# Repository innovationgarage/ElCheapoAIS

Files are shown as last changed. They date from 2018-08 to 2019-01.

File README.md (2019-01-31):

# ElCheapoAIS
AIS receiver with DIY antenna and cheap RTL-SDR tuner 

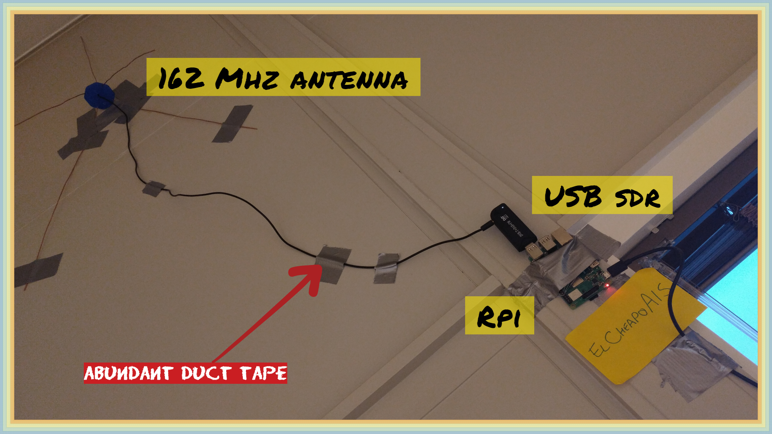
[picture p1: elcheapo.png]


## Quick guide
1. You need: Raspberry Pi, USB RTL SDR tuner, materials for building the antenna
2. Craft the antenna (_see instructions below_)
3. Install Raspbian on the RPi (tested with Stretch 4.14 Lite)
4. Prepare the destination of the AIS data (i.e. create AISHub account: http://www.aishub.net/join-us)
5. Execute `wget -q -O - https://git.io/fpVRc | sudo bash` (Alternatively, you can ignore step 5 and 6 and follow the procedure at the end of this README)
6. Follow the instructions (prepare, calibrate and install using the account details received in step 4)
7. Profit?

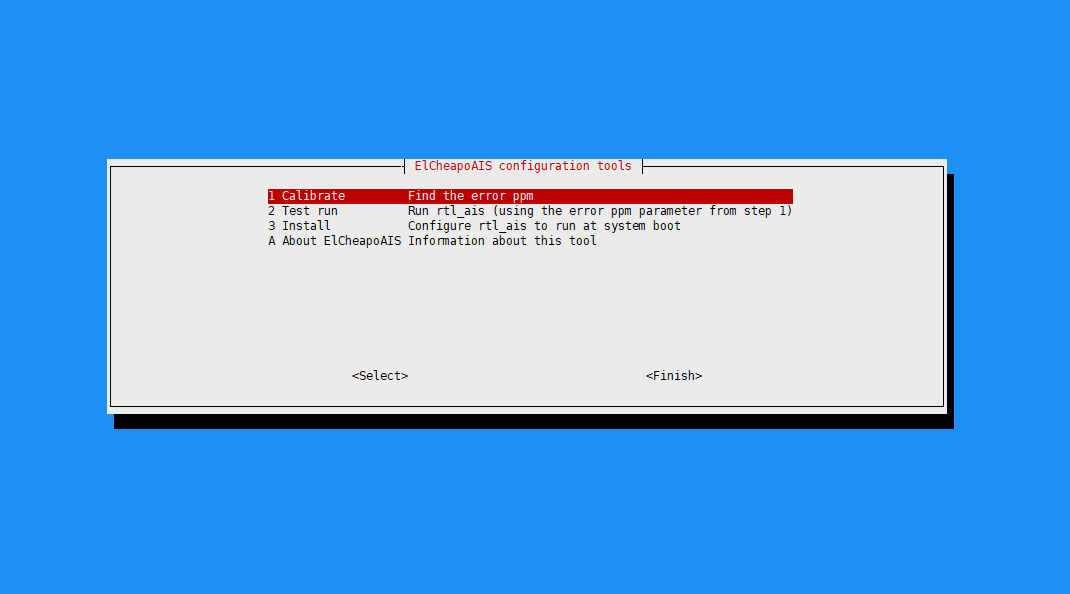
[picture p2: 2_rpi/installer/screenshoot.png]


## Hardware
* Tuner https://www.ebay.com/itm/USB2-0-DAB-FM-DVB-T-RTL2832U-R820T2-SDR-RTL-SDR-Dongle-Stick-Digital-TV-Tun-W8M8/283032648261
* Antenna

### Build the antenna
Measurements, examples and building instructions are available here: https://m0ukd.com/calculators/quarter-wave-ground-plane-antenna-calculator/. The following measurements are for a 162 Mhz antenna (for best results build one around that frequency):

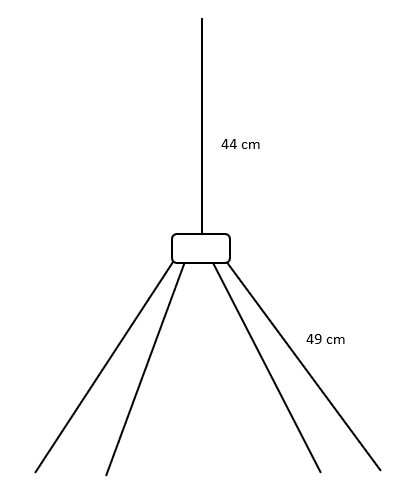
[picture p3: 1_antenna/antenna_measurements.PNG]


You can 3d print the center holder: https://www.thingiverse.com/thing:3099905

## Software

### Windows (Testing)
* AISRecWinFull https://sites.google.com/site/feverlaysoft/home
* OpenCPN
    * Set the same ip and port in OpenCPN and AISRecWinFull, and start the later

### Ubuntu

If your device is constantly in use even though you're not using it,
it's probably used by the DVB kernel driver. To use it as an SDR
receiver run the following as root before pluggin in your device:

    echo "blacklist dvb_usb_rtl28xxu" >> /etc/modprobe.d/blacklist.conf

### Raspbian/Raspberry Pi
Using kalibrate-rtl and rtl-ais.

#### Setup

      sudo apt install build-essential libtool m4 automake libfftw3-dev automake autoconf
      git clone https://github.com/steve-m/kalibrate-rtl
      cd kalibrate-rtl
      ./bootstrap && CXXFLAGS='-W -Wall -O3'
      ./configure
      make
      sudo make install

Now scan for base stations

      kal -g 42 -e 22 -s 850
      kal -g 42 -e 22 -s 900
      etc…
      
Example output

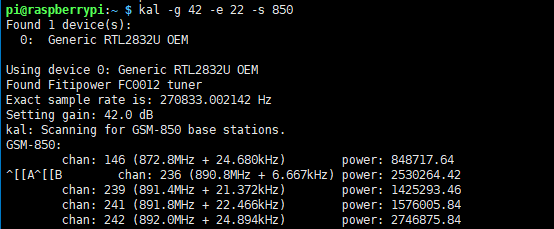
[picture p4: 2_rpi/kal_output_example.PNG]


Find ppm error using the strongest channel from previous attempts

      kal -e 41 -c <strongest channel> -v
      
Example output

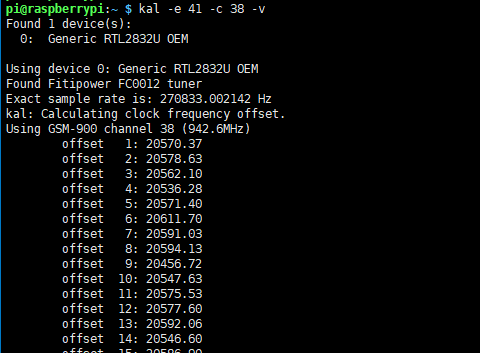
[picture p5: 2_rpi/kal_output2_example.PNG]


Copy the `ppm` value at the end of the output from the last step. You can write decimals in the `-p` argument, but it will parsed as integer.

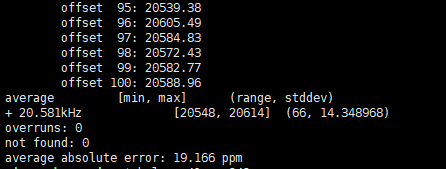
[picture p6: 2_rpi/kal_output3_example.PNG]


Compile rtl_ais

      sudo apt install git librtlsdr-dev libusb-dev libpthread-workqueue-dev
      git clone https://github.com/dgiardini/rtl-ais 		
      cd rtl-ais
      make

Run rtl_ais

      sudo ./rtl_ais -n -h <UDP_SERVER> -P <PORT_SERVER> -p <PPM_ERROR> -g 60 -S 60

Done!

#### Test

    sudo ./rtl_ais -n -h <UDP_SERVER> -P <PORT_SERVER> -p <PPM_ERROR> -g 60 -S 60

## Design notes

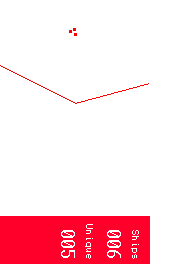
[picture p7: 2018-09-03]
2_rpi/epaper_screen/epaper_dual/red.bmp

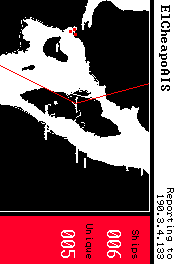
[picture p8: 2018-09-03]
2_rpi/epaper_screen/epaper_dual/black.bmp

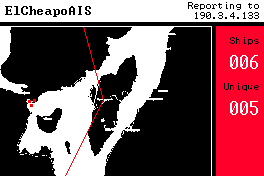
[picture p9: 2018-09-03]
2_rpi/epaper_screen/demo.png

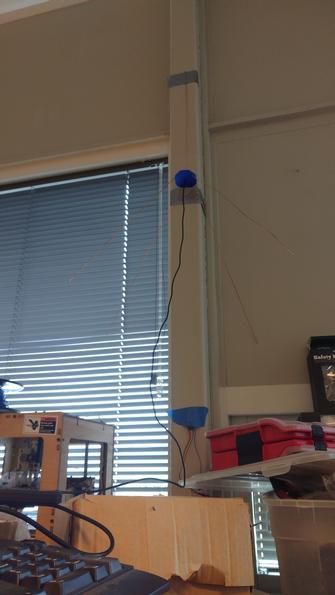
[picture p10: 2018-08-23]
antenna.jpg

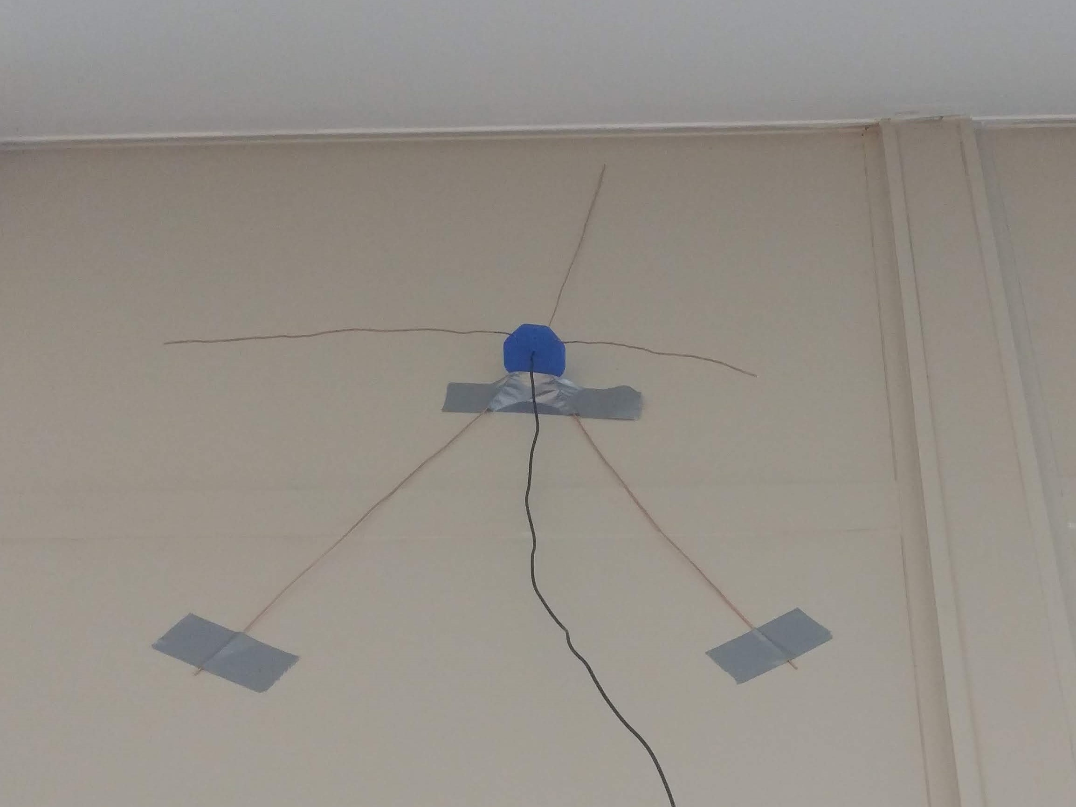
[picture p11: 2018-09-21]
1_antenna/cover.jpg

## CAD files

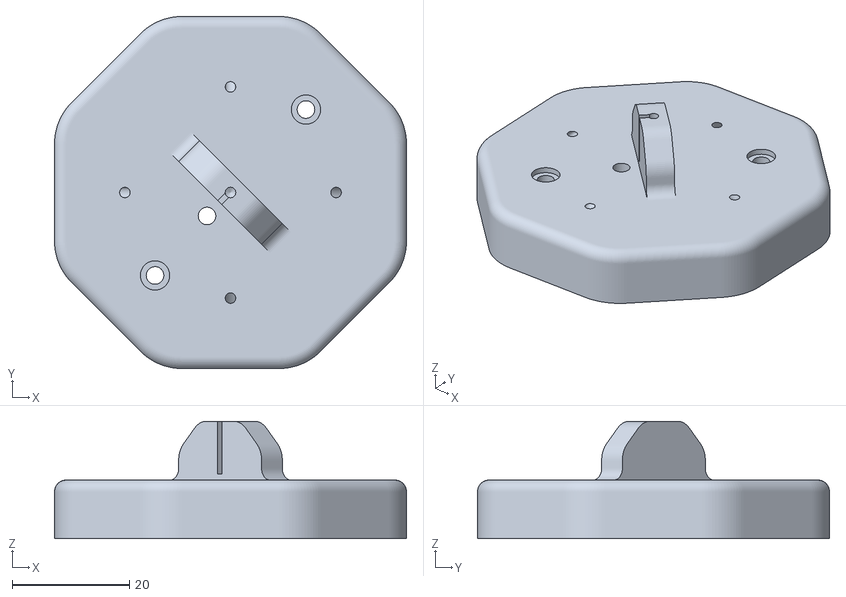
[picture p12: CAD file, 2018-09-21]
1_antenna/holder.stl
60.0 x 60.0 x 20.0

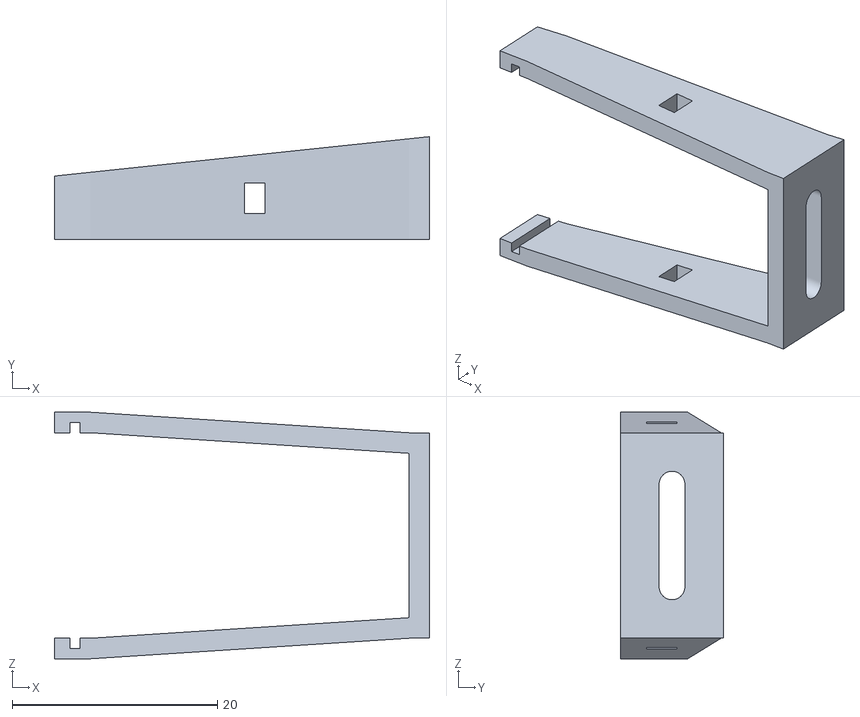
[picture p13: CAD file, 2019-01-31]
3_prototype/mount/holder.stl
36.5 x 10.0 x 24.0

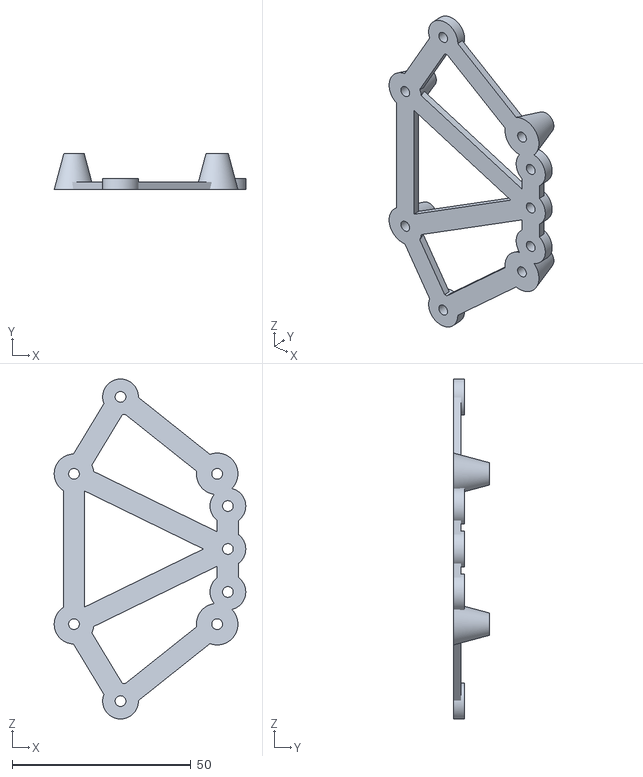
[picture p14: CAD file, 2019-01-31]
3_prototype/mount/mount.stl
53.5 x 10.0 x 95.0

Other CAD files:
1_antenna/OldVersions/holder.0002.ipt
1_antenna/holder.ipt
3_prototype/mount/OldVersions/holder.0001.ipt
3_prototype/mount/OldVersions/mount.0001.ipt
3_prototype/mount/holder.ipt
3_prototype/mount/mount.ipt

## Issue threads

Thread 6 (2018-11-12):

Better / automatic setup

redhog, 2018-11-12:
apt install rtl-sdr

This allows you to store up to 12 characters as a "version number" on the device

    rtl_eeprom -s "abcdabcdabcd"

which can be used to identify the device and know if we need to calibrate the device. However, the new serial number is only visible after a plug/unplug cycle! Unbinding / rebinding the driver (e.g. "echo 1-1.4 > /sys/bus/usb/drivers/usb/unbind") did not help.

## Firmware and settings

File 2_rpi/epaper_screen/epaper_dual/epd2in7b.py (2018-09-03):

##
 #  @filename   :   epd2in7b.py
 #  @brief      :   Implements for Dual-color e-paper library
 #  @author     :   Yehui from Waveshare
 #
 #  Copyright (C) Waveshare     July 31 2017
 #
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

import epdif
import Image
import ImageDraw
import ImageFont
import RPi.GPIO as GPIO

# Display resolution
EPD_WIDTH       = 176
EPD_HEIGHT      = 264

# EPD2IN7B commands
PANEL_SETTING                               = 0x00
POWER_SETTING                               = 0x01
POWER_OFF                                   = 0x02
POWER_OFF_SEQUENCE_SETTING                  = 0x03
POWER_ON                                    = 0x04
POWER_ON_MEASURE                            = 0x05
BOOSTER_SOFT_START                          = 0x06
DEEP_SLEEP                                  = 0x07
DATA_START_TRANSMISSION_1                   = 0x10
DATA_STOP                                   = 0x11
DISPLAY_REFRESH                             = 0x12
DATA_START_TRANSMISSION_2                   = 0x13
PARTIAL_DATA_START_TRANSMISSION_1           = 0x14
PARTIAL_DATA_START_TRANSMISSION_2           = 0x15
PARTIAL_DISPLAY_REFRESH                     = 0x16
LUT_FOR_VCOM                                = 0x20
LUT_WHITE_TO_WHITE                          = 0x21
LUT_BLACK_TO_WHITE                          = 0x22
LUT_WHITE_TO_BLACK                          = 0x23
LUT_BLACK_TO_BLACK                          = 0x24
PLL_CONTROL                                 = 0x30
TEMPERATURE_SENSOR_COMMAND                  = 0x40
TEMPERATURE_SENSOR_CALIBRATION              = 0x41
TEMPERATURE_SENSOR_WRITE                    = 0x42
TEMPERATURE_SENSOR_READ                     = 0x43
VCOM_AND_DATA_INTERVAL_SETTING              = 0x50
LOW_POWER_DETECTION                         = 0x51
TCON_SETTING                                = 0x60
TCON_RESOLUTION                             = 0x61
SOURCE_AND_GATE_START_SETTING               = 0x62
GET_STATUS                                  = 0x71
AUTO_MEASURE_VCOM                           = 0x80
VCOM_VALUE                                  = 0x81
VCM_DC_SETTING_REGISTER                     = 0x82
PROGRAM_MODE                                = 0xA0
ACTIVE_PROGRAM                              = 0xA1
READ_OTP_DATA                               = 0xA2

# Display orientation
ROTATE_0                                    = 0
ROTATE_90                                   = 1
ROTATE_180                                  = 2
ROTATE_270                                  = 3

class EPD:
    def __init__(self):
        self.reset_pin = epdif.RST_PIN
        self.dc_pin = epdif.DC_PIN
        self.busy_pin = epdif.BUSY_PIN
        self.width = EPD_WIDTH
        self.height = EPD_HEIGHT
        self.rotate = ROTATE_0

    lut_vcom_dc = [
        0x00    ,0x00,
        0x00    ,0x1A    ,0x1A    ,0x00    ,0x00    ,0x01,        
        0x00    ,0x0A    ,0x0A    ,0x00    ,0x00    ,0x08,        
        0x00    ,0x0E    ,0x01    ,0x0E    ,0x01    ,0x10,        
        0x00    ,0x0A    ,0x0A    ,0x00    ,0x00    ,0x08,        
        0x00    ,0x04    ,0x10    ,0x00    ,0x00    ,0x05,        
        0x00    ,0x03    ,0x0E    ,0x00    ,0x00    ,0x0A,        
        0x00    ,0x23    ,0x00    ,0x00    ,0x00    ,0x01    
    ]

    # R21H
    lut_ww = [
        0x90    ,0x1A    ,0x1A    ,0x00    ,0x00    ,0x01,
        0x40    ,0x0A    ,0x0A    ,0x00    ,0x00    ,0x08,
        0x84    ,0x0E    ,0x01    ,0x0E    ,0x01    ,0x10,
        0x80    ,0x0A    ,0x0A    ,0x00    ,0x00    ,0x08,
        0x00    ,0x04    ,0x10    ,0x00    ,0x00    ,0x05,
        0x00    ,0x03    ,0x0E    ,0x00    ,0x00    ,0x0A,
        0x00    ,0x23    ,0x00    ,0x00    ,0x00    ,0x01
    ]

    # R22H    r
    lut_bw = [
        0xA0    ,0x1A    ,0x1A    ,0x00    ,0x00    ,0x01,
        0x00    ,0x0A    ,0x0A    ,0x00    ,0x00    ,0x08,
        0x84    ,0x0E    ,0x01    ,0x0E    ,0x01    ,0x10,
        0x90    ,0x0A    ,0x0A    ,0x00    ,0x00    ,0x08,
        0xB0    ,0x04    ,0x10    ,0x00    ,0x00    ,0x05,
        0xB0    ,0x03    ,0x0E    ,0x00    ,0x00    ,0x0A,
        0xC0    ,0x23    ,0x00    ,0x00    ,0x00    ,0x01
    ]

    # R23H    w
    lut_bb = [
        0x90    ,0x1A    ,0x1A    ,0x00    ,0x00    ,0x01,
        0x40    ,0x0A    ,0x0A    ,0x00    ,0x00    ,0x08,
        0x84    ,0x0E    ,0x01    ,0x0E    ,0x01    ,0x10,
        0x80    ,0x0A    ,0x0A    ,0x00    ,0x00    ,0x08,
        0x00    ,0x04    ,0x10    ,0x00    ,0x00    ,0x05,
        0x00    ,0x03    ,0x0E    ,0x00    ,0x00    ,0x0A,
        0x00    ,0x23    ,0x00    ,0x00    ,0x00    ,0x01
    ]

    # R24H    b
    lut_wb = [
        0x90    ,0x1A    ,0x1A    ,0x00    ,0x00    ,0x01,
        0x20    ,0x0A    ,0x0A    ,0x00    ,0x00    ,0x08,
        0x84    ,0x0E    ,0x01    ,0x0E    ,0x01    ,0x10,
        0x10    ,0x0A    ,0x0A    ,0x00    ,0x00    ,0x08,
        0x00    ,0x04    ,0x10    ,0x00    ,0x00    ,0x05,
        0x00    ,0x03    ,0x0E    ,0x00    ,0x00    ,0x0A,
        0x00    ,0x23    ,0x00    ,0x00    ,0x00    ,0x01
    ]

    def digital_write(self, pin, value):
        epdif.epd_digital_write(pin, value)

    def digital_read(self, pin):
        return epdif.epd_digital_read(pin)

    def delay_ms(self, delaytime):
        epdif.epd_delay_ms(delaytime)

    def send_command(self, command):
        self.digital_write(self.dc_pin, GPIO.LOW)
        # the parameter type is list but not int
        # so use [command] instead of command
        epdif.spi_transfer([command])

    def send_data(self, data):
        self.digital_write(self.dc_pin, GPIO.HIGH)
        # the parameter type is list but not int
        # so use [data] instead of data
        epdif.spi_transfer([data])

    def init(self):
        if (epdif.epd_init() != 0):
            return -1
        self.reset()

        self.send_command(POWER_ON)
        self.wait_until_idle()

        self.send_command(PANEL_SETTING)
        self.send_data(0xaf)        #KW-BF   KWR-AF    BWROTP 0f
        
        self.send_command(PLL_CONTROL)
        self.send_data(0x3a)       #3A 100HZ   29 150Hz 39 200HZ    31 171HZ

        self.send_command(POWER_SETTING)
        self.send_data(0x03)                  # VDS_EN, VDG_EN
        self.send_data(0x00)                  # VCOM_HV, VGHL_LV[1], VGHL_LV[0]
        self.send_data(0x2b)                  # VDH
        self.send_data(0x2b)                  # VDL
        self.send_data(0x09)                  # VDHR

        self.send_command(BOOSTER_SOFT_START)
        self.send_data(0x07)
        self.send_data(0x07)
        self.send_data(0x17)

        # Power optimization
        self.send_command(0xF8)
        self.send_data(0x60)
        self.send_data(0xA5)

        # Power optimization
        self.send_command(0xF8)
        self.send_data(0x89)
        self.send_data(0xA5)
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

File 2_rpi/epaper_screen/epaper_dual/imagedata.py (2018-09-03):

##
 #  @filename   :   imagedata.py
 #  @brief      :   data file for epd demo
 #
 #  Copyright (C) Waveshare     July 4 2017
 #
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


IMAGE_BLACK = [ # 0X01,0X01,0X08,0X01,0XB0,0X00, #
0X00,0X00,0X00,0X00,0X00,0X00,0X00,0X00,0X00,0X00,0X00,0X00,0X00,0X00,0X00,0X00,
0X00,0X00,0X00,0X00,0X00,0X00,0X00,0X00,0X00,0X00,0X00,0X00,0X00,0X00,0X00,0X00,
0X00,0X00,0X00,0X00,0X00,0X00,0X00,0X00,0X00,0X00,0X00,0X00,0X00,0X00,0X00,0X00,
0X00,0X00,0X00,0X00,0X00,0X00,0X00,0X00,0X00,0X00,0X00,0X00,0X00,0X00,0X00,0X00,
0X00,0X00,0X00,0X00,0X00,0X00,0X00,0X00,0X00,0X00,0X00,0X00,0X00,0X00,0X00,0X00,
0X00,0X00,0X00,0X00,0X00,0X00,0X00,0X00,0X00,0X00,0X00,0X00,0X00,0X00,0X00,0X00,
0X00,0X00,0X00,0X00,0X00,0X00,0X00,0X00,0X00,0X00,0X00,0X00,0X00,0X00,0X00,0X00,
0X00,0X00,0X00,0X00,0X00,0X00,0X00,0X00,0X00,0X00,0X00,0X00,0X00,0X00,0X00,0X00,
0X00,0X00,0X00,0X00,0X00,0X00,0X00,0X00,0X00,0X00,0X00,0X00,0X00,0X00,0X00,0X00,
0X00,0X00,0X00,0X00,0X00,0X00,0X00,0X00,0X00,0X00,0X00,0X00,0X00,0X00,0X00,0X00,
0X00,0X00,0X00,0X00,0X00,0X00,0X00,0X00,0X00,0X00,0X00,0X00,0X00,0X00,0X00,0X00,
0X00,0X00,0X00,0X00,0X00,0X00,0X00,0X00,0X00,0X00,0X00,0X00,0X00,0X00,0X00,0X00,
0X00,0X00,0X00,0X00,0X00,0X00,0X00,0X00,0X00,0X00,0X00,0X00,0X00,0X00,0X00,0X00,
0X00,0X00,0X00,0X00,0X00,0X00,0X00,0X00,0X00,0X00,0X00,0X00,0X00,0X00,0X00,0X00,
0X00,0X00,0X00,0X00,0X00,0X00,0X00,0X00,0X00,0X00,0X00,0X00,0X00,0X00,0X00,0X00,
0X00,0X00,0X00,0X00,0X00,0X00,0X00,0X00,0X00,0X00,0X00,0X00,0X00,0X00,0X00,0X00,
0X00,0X00,0X00,0X00,0X00,0X00,0X00,0X00,0X00,0X00,0X00,0X00,0X00,0X00,0X00,0X00,
0X00,0X00,0X00,0X00,0X00,0X00,0X00,0X00,0X00,0X00,0X00,0X00,0X00,0X00,0X00,0X00,
0X00,0X00,0X00,0X00,0X00,0X00,0X00,0X00,0X00,0X00,0X00,0X00,0X00,0X00,0X00,0X00,
0X00,0X00,0X00,0X00,0X00,0X00,0X00,0X00,0X00,0X00,0X00,0X00,0X00,0X00,0X00,0X00,
0X00,0X00,0X00,0X00,0X00,0X00,0X00,0X00,0X00,0X00,0X00,0X00,0X00,0X00,0X00,0X00,
0X00,0X00,0X00,0X00,0X00,0X00,0X00,0X00,0X00,0X00,0X00,0X00,0X00,0X00,0X00,0X00,
0X00,0X00,0X00,0X00,0X00,0X00,0X00,0X00,0X00,0X00,0X00,0X00,0X00,0X00,0X00,0X00,
0X00,0X00,0X00,0X00,0X00,0X00,0X00,0X00,0X00,0X00,0X00,0X00,0X00,0X00,0X00,0X00,
0X00,0X00,0X00,0X00,0X00,0X00,0X00,0X00,0X00,0X00,0X00,0X00,0X00,0X00,0X00,0X00,
0X00,0X00,0X00,0X00,0X00,0X00,0X00,0X00,0X00,0X00,0X00,0X00,0X00,0X00,0X00,0X00,
0X00,0X00,0X00,0X00,0X00,0X00,0X00,0X00,0X00,0X00,0X00,0X00,0X00,0X00,0X00,0X00,
0X00,0X00,0X00,0X00,0X00,0X00,0X00,0X00,0X00,0X00,0X00,0X00,0X00,0X00,0X00,0X00,
0X00,0X00,0X00,0X00,0X00,0X00,0X00,0X00,0X00,0X00,0X00,0X00,0X00,0X00,0X00,0X00,
0X00,0X00,0X00,0X00,0X00,0X00,0X00,0X01,0X00,0X00,0X00,0X00,0X00,0X00,0X00,0X00,
0X00,0X00,0X00,0X00,0X00,0X00,0X00,0X00,0X00,0X00,0X00,0X00,0X00,0X01,0XC0,0X00,
0X00,0X00,0X00,0X00,0X00,0X00,0X00,0X00,0X00,0X00,0X00,0X00,0X00,0X00,0X00,0X00,
0X00,0X00,0X00,0X00,0X60,0X00,0X00,0X00,0X00,0X00,0X00,0X00,0X00,0X00,0X00,0X00,
0X00,0X00,0X00,0X00,0X00,0X00,0X00,0X00,0X00,0X00,0X30,0X00,0X00,0X00,0X00,0X00,
0X00,0X00,0X00,0X00,0X00,0X00,0X00,0X00,0X00,0X00,0X00,0X00,0X00,0X00,0X00,0X00,
0X18,0X00,0X00,0X00,0X00,0X00,0X00,0X00,0X00,0X00,0X00,0X00,0X00,0X00,0X00,0X00,
0X00,0X00,0X00,0X00,0X00,0X00,0X0C,0X00,0X00,0X00,0X00,0X00,0X00,0X00,0X00,0X00,
0X00,0X00,0X00,0X00,0X00,0X00,0X00,0X00,0X00,0X00,0X00,0X00,0X06,0X00,0X00,0X00,
0X00,0X00,0X00,0X00,0X00,0X00,0X00,0X00,0X00,0X00,0X00,0X00,0X00,0X00,0X00,0X00,
0X00,0X00,0X07,0X00,0X00,0X00,0X00,0X00,0X00,0X00,0X00,0X00,0X00,0X00,0X00,0X00,
0X00,0X00,0X00,0X00,0X00,0X00,0X00,0X00,0X03,0X80,0X00,0X00,0X00,0X00,0X00,0X00,
0X00,0X00,0X00,0X00,0X00,0X00,0X00,0X00,0X00,0X00,0X00,0X00,0X00,0X00,0X01,0XC0,
0X00,0X00,0X00,0X00,0X00,0X00,0X00,0X00,0X00,0X00,0X00,0X00,0X00,0X00,0X00,0X00,
0X00,0X00,0X00,0X00,0X00,0XE0,0X00,0X00,0X00,0X00,0X00,0X00,0X00,0X00,0X00,0X00,
0X00,0X00,0X00,0X00,0X00,0X00,0X00,0X00,0X00,0X00,0X00,0XF0,0X00,0X00,0X00,0X00,
0X00,0X00,0X00,0X00,0X00,0X00,0X00,0X00,0X00,0X00,0X00,0X00,0X00,0X00,0X00,0X00,
0X00,0X78,0X00,0X00,0X00,0X00,0X00,0X00,0X00,0X00,0X00,0X00,0X00,0X00,0X00,0X00,
0X00,0X00,0X00,0X00,0X00,0X00,0X00,0X3C,0X00,0X00,0X00,0X00,0X00,0X00,0X00,0X00,
0X08,0X00,0X00,0X00,0X00,0X00,0X00,0X00,0X00,0X00,0X00,0X00,0X00,0X1C,0X00,0X00,
0X00,0X00,0X00,0X00,0X00,0X00,0X08,0X00,0X00,0X00,0X00,0X00,0X00,0X00,0X00,0X00,
0X00,0X00,0X00,0X1E,0X00,0X00,0X00,0X00,0X00,0X00,0X00,0X00,0X0C,0X00,0X00,0X00,
0X00,0X00,0X00,0X00,0X00,0X00,0X00,0X00,0X00,0X0F,0X00,0X00,0X00,0X00,0X00,0X00,
0X00,0X00,0X0C,0X00,0X00,0X00,0X00,0X00,0X00,0X00,0X00,0X00,0X00,0X00,0X00,0X07,
0X80,0X00,0X00,0X00,0X00,0X00,0X00,0X00,0X0C,0X00,0X00,0X00,0X00,0X00,0X00,0X00,
0X00,0X00,0X00,0X00,0X00,0X00,0X00,0X00,0X00,0X00,0X00,0X00,0X00,0X00,0X0E,0X00,
0X00,0X00,0X00,0X00,0X00,0X00,0X00,0X00,0X00,0X00,0X00,0X00,0X00,0X00,0X00,0X00,
0X00,0X00,0X00,0X00,0X1E,0X00,0X00,0X00,0X00,0X00,0X00,0X00,0X00,0X00,0X00,0X00,
0X00,0X00,0X00,0X00,0X00,0X00,0X00,0X00,0X00,0X00,0X1E,0X00,0X00,0X00,0X00,0X00,
0X00,0X00,0X00,0X00,0X00,0X00,0X00,0X00,0X00,0X00,0X00,0X00,0X00,0X00,0X00,0X00,
0X1E,0X00,0X00,0X00,0X00,0X00,0X00,0X00,0X00,0X00,0X00,0X00,0X00,0X00,0X00,0X00,
0X00,0X00,0X00,0X00,0X00,0X00,0X1F,0X00,0X00,0X00,0X00,0X00,0X00,0X00,0X00,0X00,
0X00,0X00,0X00,0X00,0X00,0X00,0X00,0X00,0X00,0X00,0X00,0X00,0X1F,0X00,0X00,0X00,
0X00,0X00,0X00,0X00,0X00,0X00,0X00,0X00,0X00,0X00,0X00,0X00,0X00,0X00,0X00,0X00,
0X00,0X00,0X1F,0X00,0X00,0X00,0X00,0X00,0X00,0X00,0X00,0X00,0X00,0X00,0X00,0X00,
0X00,0X00,0X00,0X00,0X00,0X00,0X00,0X00,0X3F,0X80,0X00,0X00,0X00,0X00,0X00,0X00,
0X00,0X00,0X00,0X00,0X00,0X00,0X00,0X00,0X00,0X00,0X00,0X00,0X00,0X00,0X3F,0X80,
0X00,0X00,0X00,0X00,0X00,0X00,0X00,0X00,0X00,0X00,0X00,0X00,0X00,0X00,0X00,0X00,
0X00,0X00,0X00,0X00,0X3F,0X80,0X00,0X00,0X00,0X00,0X00,0X00,0X00,0X00,0X00,0X00,
0X00,0X00,0X00,0X00,0X00,0X00,0X00,0X00,0X00,0X00,0X3F,0XC0,0X00,0X00,0X00,0X00,
0X00,0X00,0X00,0X00,0X00,0X00,0X00,0X00,0X00,0X00,0X00,0X00,0X00,0X00,0X00,0X00,
0X3F,0XC0,0X00,0X00,0X00,0X00,0X00,0X00,0X00,0X00,0X00,0X00,0X00,0X00,0X00,0X00,
0X00,0X00,0X00,0X00,0X00,0X00,0X3F,0XE0,0X00,0X00,0X00,0X00,0X00,0X00,0X00,0X00,
0X00,0X00,0X00,0X00,0X00,0X00,0X00,0X00,0X00,0X00,0X00,0X00,0X3F,0XE0,0X00,0X00,
0X00,0X00,0X00,0X00,0X00,0X00,0X00,0X00,0X00,0X00,0X00,0X00,0X00,0X00,0X00,0X00,
0X00,0X00,0X7F,0XF0,0X00,0X00,0X00,0X00,0X00,0X00,0X00,0X00,0X00,0X00,0X00,0X00,
0X00,0X00,0X00,0X00,0X00,0X00,0X00,0X00,0X7F,0XF0,0X00,0X00,0X00,0X00,0X00,0X00,
0X00,0X00,0X00,0X00,0X00,0X00,0X00,0X00,0X00,0X00,0X00,0X00,0X00,0X00,0X7F,0XF0,
0X00,0X00,0X00,0X00,0X00,0X00,0X00,0X00,0X00,0X00,0X00,0X00,0X00,0X00,0X00,0X00,
0X00,0X00,0X00,0X00,0X7F,0XF0,0X00,0X00,0X00,0X00,0X00,0X00,0X00,0X00,0X00,0X00,
0X00,0X00,0X00,0X00,0X00,0X00,0X00,0X00,0X00,0X00,0X7F,0XE0,0X00,0X00,0X00,0X00,
0X00,0X00,0X00,0X00,0X00,0X00,0X00,0X00,0X00,0X00,0X00,0X00,0X00,0X00,0X00,0X00,
0X7F,0XE0,0X00,0X00,0X00,0X00,0X00,0X00,0X00,0X00,0X00,0X00,0X00,0X00,0X00,0X00,
0X00,0X00,0X00,0X00,0X00,0X00,0X7F,0XC0,0X00,0X00,0X00,0X00,0X00,0X00,0X00,0X00,
0X00,0X00,0X00,0X00,0X00,0X00,0X00,0X00,0X00,0X00,0X04,0X00,0X7F,0XC0,0X00,0X00,
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

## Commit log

2018-08-16 Antenna design
2018-08-16 Ground plane holder
    [holder.0002.ipt, holder.ipt]
2018-08-22 Antenna measurements
2018-09-03 Screen driver
2018-09-21 Thingiverse 3d file and cover
    [holder.stl]
2018-11-13 Read/write calibration shell functions
2018-11-13 Service that does calibration if not already calibrated
2018-11-13 New calibrate-at-boot system
2018-11-13 Brought back calibrate and test run menu entries
2018-11-14 Proper options for elcheapo-calibrate.sh
2019-01-31 Mount for the prototype box
    [holder.0001.ipt, holder.ipt, holder.stl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]
2019-01-31 Extension board Gerber
